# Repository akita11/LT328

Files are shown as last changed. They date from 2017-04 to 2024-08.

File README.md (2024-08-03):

# LED Tile328の関連ファイル。

## インストールと動作チェック

詳しい使い方は LT328man_v100.pdf を参照してください。以下は概要です。

1. ファイルをzipでダウンロード(右のほうの緑の"clone or Download"から)
2. ArduinoIDEから、スケッチ→ライブラリをインクルード→ZIP形式のライブラリをインストール、を選び、1.でダウンロードしたzipファイルを選ぶ。ライブラリに"LT328v2"が追加されていることを確認する
3. ArduinoIDEのツール→ボードから、"Arduino Pro or Pro Mini"を選び、プロセッサから"ATmega328(3.3V, 8MHz)"を選ぶ
4. LED TileとPCをmicroUSBケーブルで接続し、ArduinoIDEでシリアルポートを設定する
5. スケッチの例として"flow"を選び、コンパイルして転送すると、明るい光（レーザーポインタ光やスマホカメラのライトなど）があたったところのLEDが点灯し、本体を傾けるとその方向に模様が流れる ※使う加速度センサがMMA7660(LT328v2)の場合は、LT328v2.hでコメントアウトされている USE_MMA7660 のdefineを戻してください。ADXL345(LT328v3)の場合はそのままでOKです
6. Arduinoディレクトリ内のlibraries/LT328v2/board 以下に基板データが展開されますが、これは不要でしたら削除してください。

## ライブラリ関数の使い方

こちらを参照（※240803:サーバ設定の関係で現在閲覧できません。少々お待ち下さい）: https://ifdl.jp/akita/lt/

## お問い合わせ

使い方などについてのお問い合わせは、Junichi Akita (akita[at]ifdl.jp / @akita11)までご連絡ください。

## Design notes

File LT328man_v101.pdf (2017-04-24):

LED Tile328 (ver2)
Ver1.00 by akita11 (akita@ifdl.jp)

０．概要

特徴
・ 可視光（LED 懐中電灯やレーザーポインタ光・明るい LED 光等）を入力できます ・ 8×8 のマトリクス LED ユニットしても使用できます
・ 3 軸加速度センサが載っています（傾き等を検出可能）
・ 4 方向の連結拡張用コネクタあり（ピンヘッダやマグネット等） ・ ArduinoIDE でプログラミング可能（ライブラリあり）

１．まずは使ってみましょう

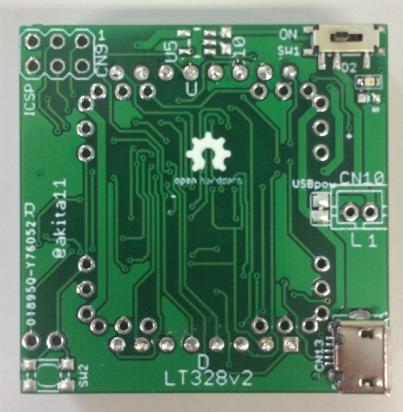
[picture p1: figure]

microUSB ケーブルを用意してください。本品の裏面にある電源スイッチが「ON」にな っていることを確認し、microUSB ケーブルを本品の microUSB コネクタに差し込み、 microUSB ケーブルの反対側を、PC の USB ポートや USB-AC アダプタ等に接続します。 マトリクス LED に広がる模様が現れ、動作が開始します。 この状態で、スマホのカメラのライトや LED 懐中電灯、レーザーポインター等の明るい 光をあてると、あたったところの LED が点灯します。また本品を傾けると、その方向に描 いたパターンが流れていきます。

２．サンプルプログラムを書き込んでみましょう

１． ArduinoIDE を http://arduino.cc からダウンロードし、PC にインストールしておき ます。（すでにインストール済みの場合は不要）
２． https://github.com/akita11/LT328 からライブラリ・サンプルプログラム一式を、この ページの右にある「Download」から zip 形式でダウンロードします。
３． ArduinoIDE の「ライブラリ」→「ライブラリをインクルード」→「.ZIP 形式のライブ ラリをインストール」から、2.でダウンロードした zip ファイルを指定します。

４． ArduinoIDE の「ツール」→「ボード」から、「Arduino Pro or Pro Mini」を選び、「ツ ール」→「プロセッサ」から、「ATmega328 (3.3V, 8MHz)」を選択します。また「ツ ール」→「シリアルポート」から、LED Tile が接続されている COM ポートを選択し ます。
５． ArduinoIDE の「ファイル」→「スケッチ例」の中の下のほうに、「LT328v2」という 項目があり、ここに LED Tile 用のサンプルが入っています。例えば”draw”を選び、 「スケッチ」→「マイコンボードに書き込む」からスケッチを書き込みます（通常の Arduino と操作は同じ）。書き込み中に点滅する LED はありませんが、しばらくする と書き込みが終了し、動作を開始します。

３．プログラミングをしてみよう

Arduino フォルダの libraries/LT328 にある LT328v2.h に、LED Tile 関連で利用できる関 数の一覧がありますので、サンプルスケッチとあわせて参照してください。基本的に、以下 のような関数があります。
・ ドットマトリクス LED の指定した箇所の LED を点灯・消灯
・ ドットマトリクス LED の指定した箇所の LED に光があたったかどうかを読む（光の 有無の基準のしきい値を設定する関数もあります）
・ 加速度センサの値を読む
・ 光があたった LED の動作を定義
・ 4 方向の通信（※この関数はまだ検証が十分に行われていません）

４．その先へ・・・

ライブラリ関数を用いることで、こちらの動画にあるような機能、例えば複数の LED Tile をまたがったパターンの移動や、ライフゲームも実現できます。ぜひご活用ください。 http://ifdl.jp/akita/lt/

５．その他の情報

ソースコード・設計データ一式は https://github.com/akita11/LT328 にありますので、必要 であればお使いください。また使い方に関するお問い合わせは akita@ifdl.jp までお願いし ます。

※本品は、技術サークル「テクノアルタ」の活動の一環として開発さ れたものです。https://www.technoalta.com/

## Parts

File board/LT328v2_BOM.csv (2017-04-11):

Part/Designator | Manufacture Part Number/Seeed SKU | Quantity
C1,C2,C3,C5,C8 | 302010138 | 5
C4,C9 | 302010158 | 2
C6 | 302010140 | 1
C7 | 302010111 | 1
CN13 | 320010005 | 1
F1 | 307010002 | 1
R1,R2,R3,R4,R5,R6,R7,R8 | 301010163 | 8
R9,R10 | 301010299 | 2
R11,R12 | 301010289 | 2
R13,R16 | 301010291 | 2
R14,R15 | 301010293 | 2
SW1 | 311030001 | 1
SW2 | 311020045 | 1
U1 | 310010005 | 1
U2 | 310070022 | 1
U3 | 310030099 | 1
U4 | 314080009 | 1
D2 | 304090043 | 1

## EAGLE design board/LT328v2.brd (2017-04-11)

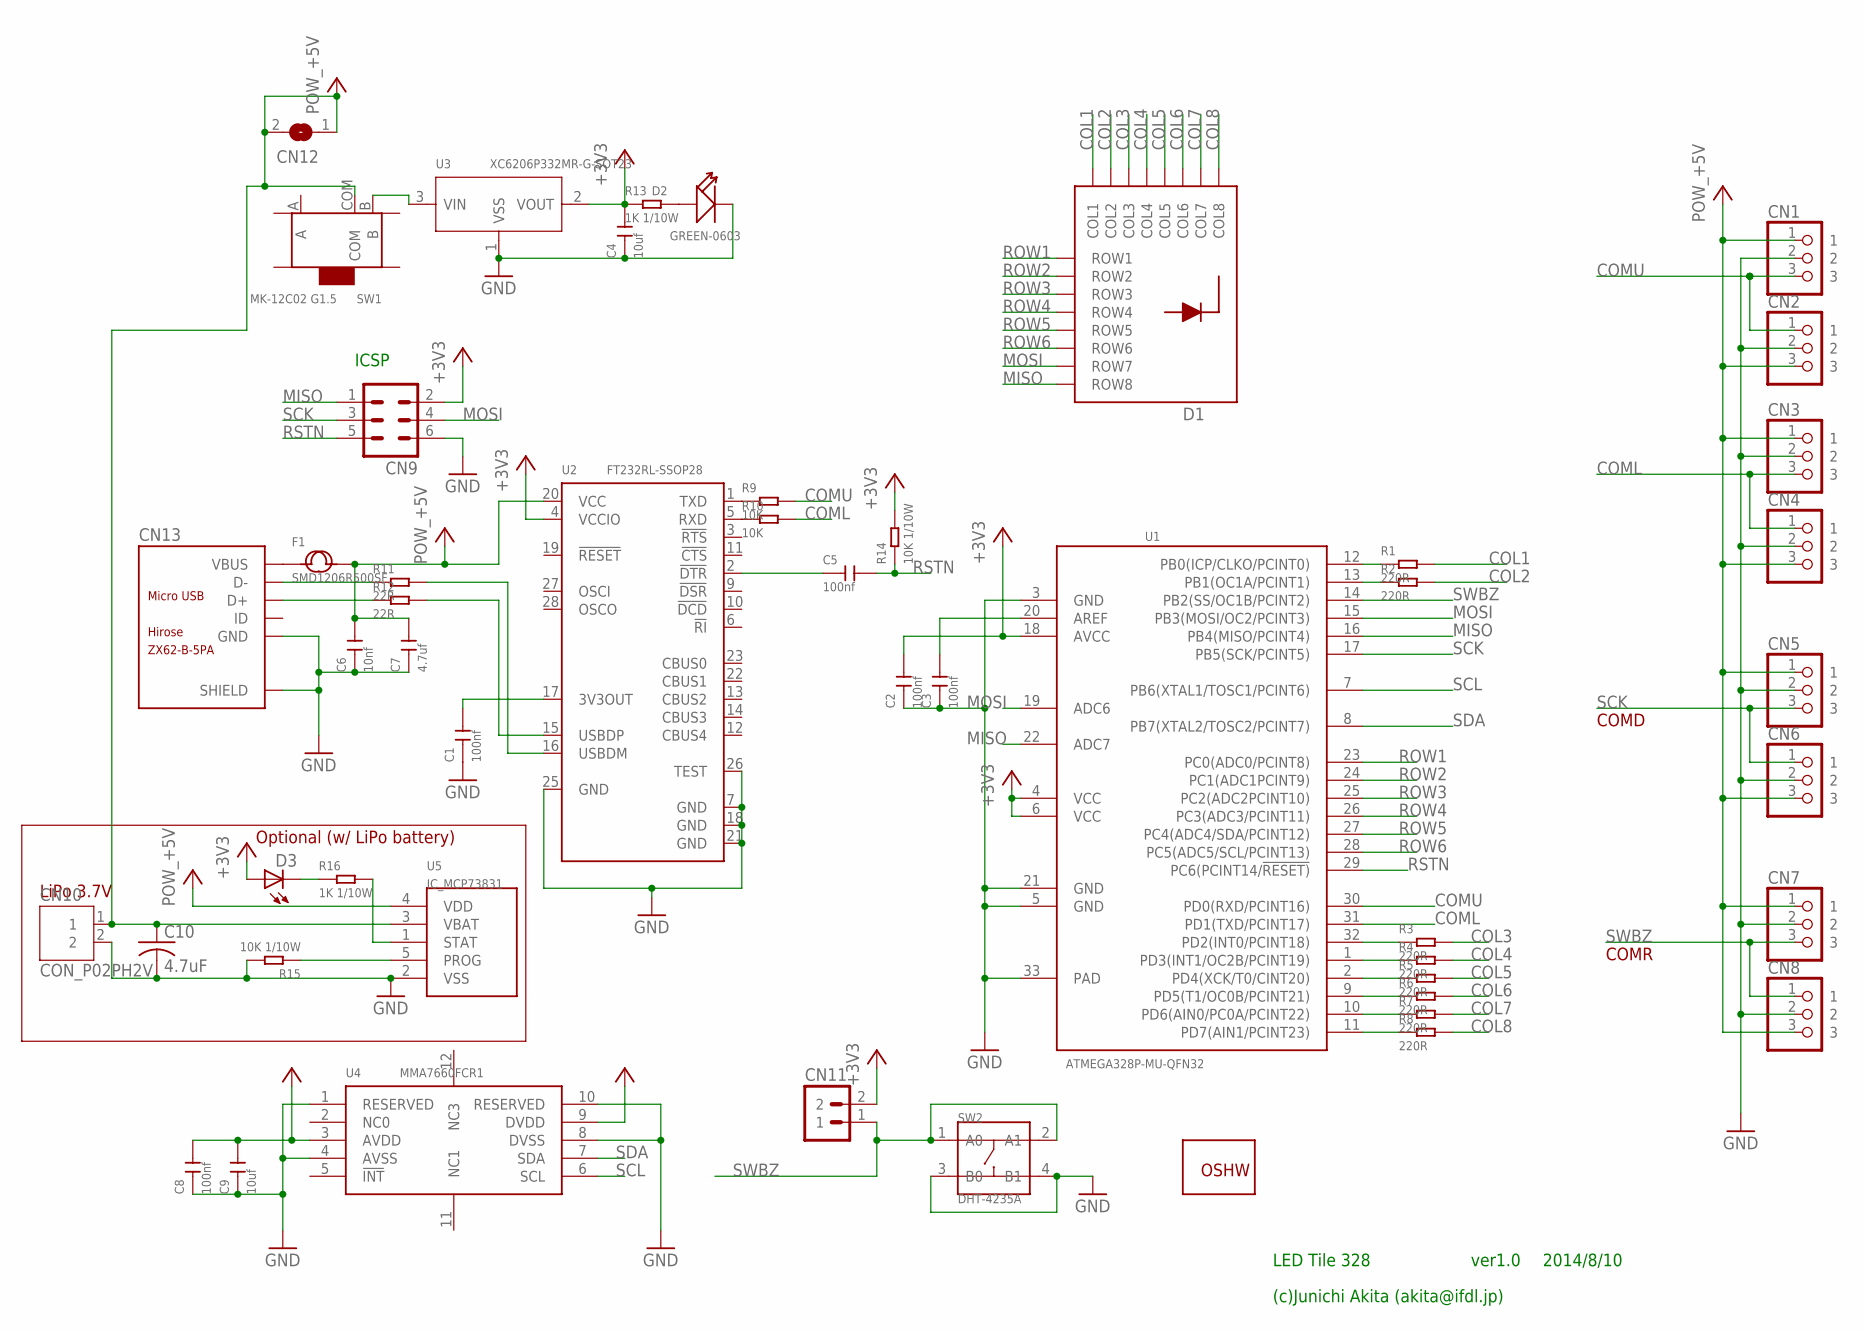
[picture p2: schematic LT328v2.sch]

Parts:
C1, C2, C3, C5, C8: 100nf; C0603
C4, C9: 10uf; C0805
C6: 10nf; C0603
C7: 4.7uf; C0603
C10: 4.7uF; C0603
CN1, CN2, CN3, CN4, CN5, CN6, CN7, CN8: CON_PINHD-1X3R; 1X03R
CN9: MA03-2
CN10: CON_P02PH2V; JST-PH2
CN11: CON_PINHD-1X2PTH; SPARKFUN_1X02
CN12: JUMPER_SJ
CN13: ZX62-B-5PA; MICRO-USB5+6P-SMD-0.65-AB
D1: LED_OSL641501BRA; TOM-1588BH
D2: GREEN-0603; LED-0603
D3: LED0603; SPARKFUN_LED-0603
F1: SMD1206R500SF; F1206
GOLD_ORB_SM1: OSHWLOGO_GOLD_ORB_SM; OSHW2
R1, R2, R3, R4, R5, R6, R7, R8: 220R; R0603
R9, R10: 10K; R0603
R11, R12: 22R; R0603
R13, R16: 1K 1/10W; R0603
R14, R15: 10K 1/10W; R0603
SW1: MK-12C02 G1.5; SW7-SMD-L6.7X2.7X3.2MM
SW2: DHT-4235A; SW4-SMD-4.2X3.2X2.5MM
U1: ATMEGA328P-MU-QFN32; QFN32G-0.5-5X5MM
U2: FT232RL-SSOP28; SSOP28-0.65-10.2X5.2MM
U3: XC6206P332MR-G-SOT23; SOT-23
U4: MMA7660FCR1; DFN10-0.5-3.0X3.0MM
U5: IC_MCP73831; SOT23-5L

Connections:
+3V3: C2.2, C4.2, C8.2, C9.2, CN9.2, CN11.2, D3.A, R13.1, R14.2, U1.4 (VCC), U1.6 (VCC), U1.18 (AVCC), U2.4 (VCCIO), U3.2 (VOUT), U4.3 (AVDD), U4.9 (DVDD)
+5V: C6.2, C7.2, C10.1, CN1.1, CN2.3, CN3.1, CN4.3, CN5.1, CN6.3, CN7.1, CN8.3, CN10.1, CN12.1, CN12.2, F1.2, SW1.COM, U2.20 (VCC), U5.3 (VBAT), U5.4 (VDD)
COL1: D1.P$13 (COL1), R1.2
COL2: D1.P$3 (COL2), R2.2
COL3: D1.P$4 (COL3), R3.2
COL4: D1.P$10 (COL4), R4.2
COL5: D1.P$6 (COL5), R5.2
COL6: D1.P$11 (COL6), R6.2
COL7: D1.P$15 (COL7), R7.2
COL8: D1.P$16 (COL8), R8.2
COML: CN3.3, CN4.1, R10.2, U1.31 (PD1(TXD/PCINT17))
COMU: CN1.3, CN2.1, R9.2, U1.30 (PD0(RXD/PCINT16))
GND: C1.1, C2.1, C3.1, C4.1, C6.1, C7.1, C8.1, C9.1, C10.2, CN1.2, CN2.2, CN3.2, CN4.2, CN5.2, CN6.2, CN7.2, CN8.2, CN9.6, CN10.2, CN13.5 (GND), CN13.P1 (SHIELD), CN13.P2 (SHIELD), CN13.P3 (SHIELD), CN13.P4 (SHIELD), CN13.P5 (SHIELD), CN13.P6 (SHIELD), D2.-, R15.2, SW2.3 (B0), SW2.4 (B1), U1.3 (GND), U1.5 (GND), U1.21 (GND), U1.33 (PAD), U2.7 (GND), U2.18 (GND), U2.21 (GND), U2.25 (GND), U2.26 (TEST), U3.1 (VSS), U4.1 (RESERVED), U4.4 (AVSS), U4.8 (DVSS), U4.10 (RESERVED), U5.2 (VSS)
MISO: CN9.1, D1.P$5 (ROW8), U1.16 (PB4(MISO/PCINT4)), U1.22 (ADC7)
MOSI: CN9.4, D1.P$2 (ROW7), U1.15 (PB3(MOSI/OC2/PCINT3)), U1.19 (ADC6)
unnamed: SW1.B, U3.3 (VIN)
unnamed: R11.2, U2.16 (USBDM)
unnamed: R12.2, U2.15 (USBDP)
unnamed: R9.1, U2.1 (TXD)
unnamed: C5.1, U2.2 (!DTR)
unnamed: C3.2, U1.20 (AREF)
unnamed: R10.1, U2.5 (RXD)
unnamed: D3.C, R16.1
unnamed: R16.2, U5.1 (STAT)
unnamed: C1.2, U2.17 (3V3OUT)
unnamed: D2.+, R13.2
unnamed: R8.1, U1.11 (PD7(AIN1/PCINT23))
unnamed: R7.1, U1.10 (PD6(AIN0/PC0A/PCINT22))
unnamed: R6.1, U1.9 (PD5(T1/OC0B/PCINT21))
unnamed: R5.1, U1.2 (PD4(XCK/T0/CINT20))
unnamed: R4.1, U1.1 (PD3(INT1/OC2B/PCINT19))
unnamed: R3.1, U1.32 (PD2(INT0/PCINT18))
unnamed: R1.1, U1.12 (PB0(ICP/CLKO/PCINT0))
unnamed: R2.1, U1.13 (PB1(OC1A/PCINT1))
unnamed: CN13.2 (D-), R11.1
unnamed: CN13.3 (D+), R12.1
unnamed: R15.1, U5.5 (PROG)
ROW1: D1.P$9 (ROW1), U1.23 (PC0(ADC0/PCINT8))
ROW2: D1.P$14 (ROW2), U1.24 (PC1(ADC1PCINT9))
ROW3: D1.P$8 (ROW3), U1.25 (PC2(ADC2PCINT10))
ROW4: D1.P$12 (ROW4), U1.26 (PC3(ADC3/PCINT11))
ROW5: D1.P$1 (ROW5), U1.27 (PC4(ADC4/SDA/PCINT12))
ROW6: D1.P$7 (ROW6), U1.28 (PC5(ADC5/SCL/PCINT13))
RSTN: C5.2, CN9.5, R14.1, U1.29 (PC6(PCINT14/!RESET))
SCK: CN5.3, CN6.1, CN9.3, U1.17 (PB5(SCK/PCINT5))
SCL: U1.7 (PB6(XTAL1/TOSC1/PCINT6)), U4.6 (SCL)
SDA: U1.8 (PB7(XTAL2/TOSC2/PCINT7)), U4.7 (SDA)
SWBZ: CN7.3, CN8.1, CN11.1, SW2.1 (A0), SW2.2 (A1), U1.14 (PB2(SS/OC1B/PCINT2))
VBUS: CN13.1 (VBUS), F1.1

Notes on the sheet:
ICSP
LiPo 3.7V
ver1.0
2014/8/10
(c)Junichi Akita (akita@ifdl.jp)
LED Tile 328
COMD
COMR
Optional (w/ LiPo battery)

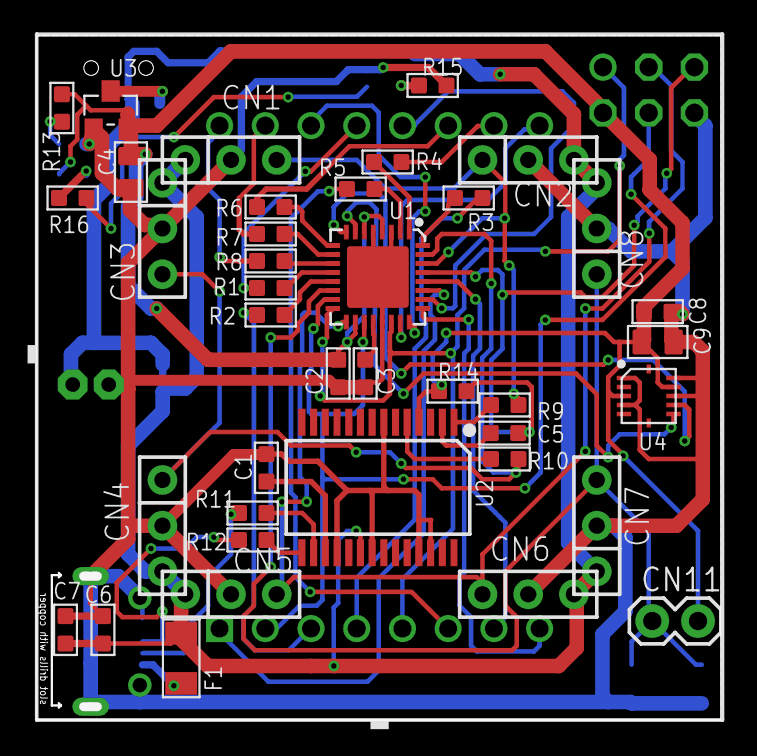
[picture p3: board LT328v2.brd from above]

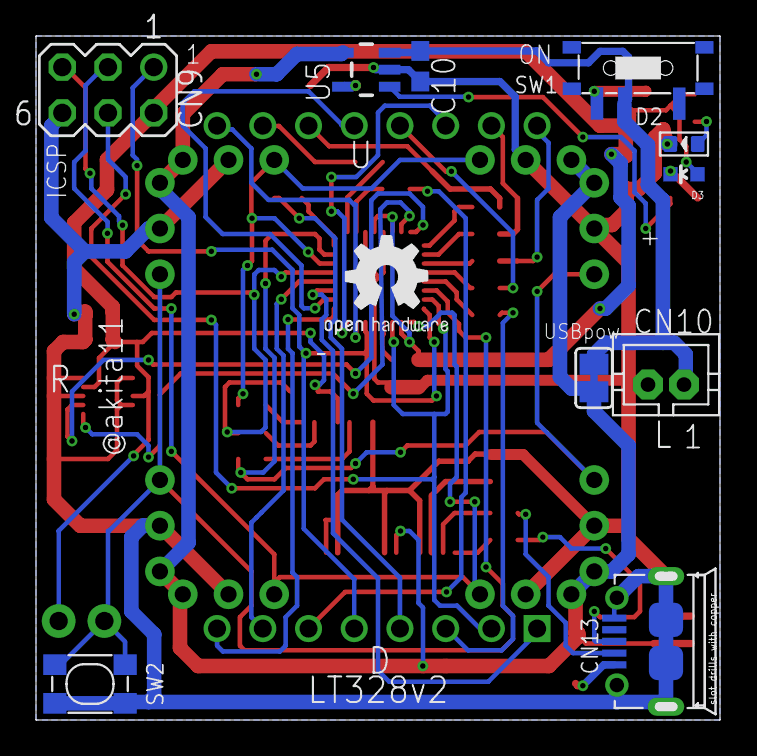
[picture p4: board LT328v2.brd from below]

Board: 2 copper layers, 38.0 x 38.0 mm, 51 parts (11 on the bottom side), 49 nets.

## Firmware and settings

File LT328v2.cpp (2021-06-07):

/*
  LT328v2.cpp - Arduino library for LED Tile, drawable 8x8 Dot Matrix LED
  based on LED_Tile328.cpp, based onDots.cpp
  Copyright 2012 akita11 (akita@ifdl.jp). All right reserved

  Dots.cpp - Arduino library for 8x8/5x7 Dot LED Matrix.
  Copyright 2010 arms22. All right reserved.
  
  This library is distributed in the hope that it will be useful,
  but WITHOUT ANY WARRANTY; without even the implied warranty of
  MERCHANTABILITY or FITNESS FOR A PARTICULAR PURPOSE. 
*/

#include <pins_arduino.h>
#include <avr/interrupt.h>
#include <LT328v2.h>
//#include <Wire.h>

void LT::set_port_dir(int pos, int num, int dir)
{
//  for BRA
//  - Col1-8(Cathode) : PB0-1/PD2-7 (via 270ohm)
//  - Row1-8(Anode)   : PC0-5/PB3-4 (ADC0-7)
  if (pos == PORT_ROW){
    if (dir == PORT_OUT){
      if (num > 7){DDRC |= 0x3f; DDRB |= 0x18;}
      else{ if (num < 6) DDRC |= 1 << num; else DDRB |= 1 << (num - 3); }
    }
    else if (dir == PORT_IN){
      if (num > 7){DDRC &= ~0x3f; DDRB &= ~0x18;}
      else{ if (num < 6) DDRC &= ~(1 << num); else DDRB &= ~(1 << (num - 3));}
    }
  }
  else if (pos == PORT_COL){
    if (dir == PORT_OUT){
      if (num > 7){ DDRD |= 0xfc; DDRB |= 0x03;}
      else{ if (num < 2) DDRB |= 1 << num; else DDRD |= 1 << num; }
    }
    else{
      if (num > 7){ DDRD &= ~0xfc; DDRB &= ~0x03;}
      else{ if (num < 2) DDRB &= ~(1 << num); else DDRD &= ~(1 << num); }
    }
  }
}

void LT::set_port_value(int pos, int num, int value)
{
//  for BRA
//  - Col1-8(Cathode) : PB0-1/PD2-7 (via 270ohm)
//  - Row1-8(Anode)   : PC0-5/PB3-4 (ADC0-7)
  if (pos == PORT_ROW){
    if (value == 1){
      if (num > 7){PORTC |= 0x3f; PORTB |= 0x18;}
      else{ if (num < 6) PORTC |= 1 << num; else PORTB |= 1 << (num - 3); }
    }
    else{
      if (num > 7){PORTC &= ~0x3f; PORTB &= ~0x18;}
      else{
	if (num < 6) PORTC &= ~(1 << num); else PORTB &= ~(1 << (num - 3));
      }
    }
  }
  else if (pos == PORT_COL){
    if (value == 1){
      if (num > 7){ PORTD |= 0xfc; PORTB |= 0x03;}
      else{ if (num < 2) PORTB |= 1 << num; else PORTD |= 1 << num; }
    }
    else{
      if (num > 7){ PORTD &= ~0xfc; PORTB &= ~0x03;}
      else{ if (num < 2) PORTB &= ~(1 << num); else PORTD &= ~(1 << num); }
    }
  }
}

LT::LT(void)
{
  _row = 0; _col = 0;
  _phase = 0;
  _raw_x = 0;
  _raw_y = 0;
  _raw_value = 0;
  _raw_value_max = 0;
  _f_raw_ready = 1;
  for (int i = 0; i < 8; i++) _th[i] = 60; // set 'default' threshold
  mode = LT_DRAW_MODE_NONE;
}

void LT::begin(uint8_t f)
{
  uint8_t i;

  set_port_value(PORT_ROW, 8, 0);
  set_port_value(PORT_COL, 8, 0); //?
  set_port_dir(PORT_ROW, 8, PORT_OUT); 
  set_port_dir(PORT_COL, 8, PORT_OUT); 
  clear();

  if (f == 1){
    for (uint8_t dir = 0; dir < 4; dir++){
      com_set_dir(dir, COM_RX);
      com_tst[dir] = 0;
      com_rst[dir] = 0;
      com_pr[dir] = 0;
      com_pb[dir] = 0;
      //      com_prb[dir] = 0;
      //      com_pbb[dir] = 0;
    }
  }
  com_operation = f;

  //  pinMode(10, INPUT_PULLUP); // for SW
  DDRB |= 0x04; PORTB |= 0x04;
  
  LT::active_object = this;

  TCCR1A = 0; // clear control register A 
  TCCR1B = _BV(WGM13); // set mode as phase and frequency correct pwm, stop the timer
  //  ICR1 = 2804;
  //  ICR1 = 3300; // 8MHz/2/3300=1.2kHz:825us / 825us*3*8=19.8ms/frame
  ICR1 = 3500;
  //  ICR1 = 3840; // 23ms/frame (43.4fps)
  TCCR1B &= ~(_BV(CS10) | _BV(CS11) | _BV(CS12));
  TCCR1B |= _BV(CS10); // no prescaler
  TIMSK1 = _BV(TOIE1); // sets the timer overflow interrupt enable bit

  DIDR0 = 0xff; // disable digital input for ADC0-7 input pins

  ADMUX = 0x60; // Vref=AVCC, left-adjust result
  //  ADMUX = 0xe0; // Vref=Vbg(1.1V), left-adjust result

  // ADC=13clk
  ADCSRA = 0x82; // ADC clock = 8MHz/4 = 2MHz
  ADCSRB |= 0x80; // ADC high speed mode
  ADCSRA |= _BV(ADSC); while ((ADCSRA & _BV(ADSC))); // initial conversion
  _f_raw_ready = 1;
  set_port_value(PORT_ROW, 8, 1); set_port_dir(PORT_ROW, 8, PORT_OUT);

  set_threshold(90); // default threshold
  i2c_setup();
#ifdef USE_ACC_MMA7660
  // initilization of MMA7660
  i2c_sendT();
  i2c_write(ACC_ADDR << 1);
  i2c_write(0x07); i2c_write(0x01); // active mode
  i2c_sendP();
#else
  // initialization of ADXL345
  i2c_sendT();
  i2c_write(ACC_ADDR << 1);
  //  i2c_write(0x16); i2c_write(0x25);
  i2c_write(0x2d); i2c_write(0x08); // Measure mode
  i2c_sendP();
  i2c_sendT();
  i2c_write(ACC_ADDR << 1);
  i2c_write(0x31); i2c_write(0x04); // +-2g, MSB-adjusted
  i2c_sendP();
#endif
}

void LT::end(void)
{
  TIMSK1 &= ~_BV(TOIE1); // disable Timer1 interrupt
  TCCR1B &= ~(_BV(CS10) | _BV(CS11) | _BV(CS12)); // stop Timer1
  LT::active_object = 0;
}

void LT::write(int x, int y, int value)
{
  uint8_t msk;
  msk = 1 << x;
  if (value == 1) pat[y] |= msk; else pat[y] &= ~msk;
}

void LT::write(int y, int value)
{
  pat[y] = value;
}

void LT::write(int y, const int values[], int size)
{
  uint8_t i;
  for(i=0;i<size;i++)
    pat[(y++) & 0x07] = values[i];
}

uint8_t LT::read(int x, int y)
{
  if (pat_in[y] & (1 << x)) return(1); else return(0);
}

uint8_t LT::read_raw(int x, int y)
{
  _raw_x = x; _raw_y = y;
  _f_raw_ready = 0;
  while(_f_raw_ready == 0);
  return(_raw_value);
}

uint8_t LT::read_raw_max(int x, int y)
{
  return(read_raw_max(x, y, 30));
}

uint8_t LT::read_raw_max(int x, int y, int N)
{
  int i;
  uint8_t v;
  _raw_value_max = 0;
  for (i = 0; i < N; i++){
    v = read_raw(x, y);
    if (v > _raw_value_max) _raw_value_max = v;
  }
  return(_raw_value_max);
}

uint8_t LT::read_raw_max(int N)
{
  int i;
  uint8_t v;
  _raw_value_max = 0;
  _raw_x = 8;
  for (i = 0; i < N; i++){
    _f_raw_ready = 0;
    while(_f_raw_ready == 0);
  }
  return(_raw_value_max);
}

uint8_t LT::read_raw_max(void)
{
  return(read_raw_max(30));
}

void LT::clear(void)
{
  uint8_t y;
  for(y=0;y<8;y++){
    pat[y] = 0;
    pat_in[y] = 0;
    _pat_in0[y] = 0;
  }
  _row = 0; _phase = 0;
}

void LT::set_threshold(int th)
{
  for (int i = 0; i < 8; i++) _th[i] = th;
}

void LT::set_threshold(int th0, int th1, int th2, int th3,
		     int th4, int th5, int th6, int th7)
{
  _th[0] = th0; _th[1] = th1; _th[2] = th2; _th[3] = th3;
  _th[4] = th4; _th[5] = th5; _th[6] = th6; _th[7] = th7;
}

void LT::set_threshold(int th[])
{
  for (int i = 0; i < 8; i++) _th[i] = th[i];
}
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

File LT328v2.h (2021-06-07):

/*
  LED_Tile328.h - Arduino library for LED Tile, drawable 8x8 Dot Matrix LED
  based on Dots.h
  Copyright 2014 akita11 (akita@ifdl.jp). All right reserved

  Dots.h - Arduino library for 8x8/5x7 Dot LED Matrix.
  Copyright 2010 arms22. All right reserved.
  
  This library is distributed in the hope that it will be useful,
  but WITHOUT ANY WARRANTY; without even the implied warranty of
  MERCHANTABILITY or FITNESS FOR A PARTICULAR PURPOSE. 
*/

#ifndef LT328V2_H
#define LT328V2_H

// uncommenct "USE_ACC_MMA7660" for LT328v3 (using ADXL345)
//#define USE_ACC_MMA7660 // use Freescale's MMA7760 as accelerometer

#include <inttypes.h>

// Dot matrix LED: OSL641501-BRA] (Akizuki's I-05163)
// Connections:
// * ATmega328P = ArduinoNano/ArduinoMini/LT328 etc.
//  - Col1-8(Cathode) : PB0-1/PD2-7 (via 270ohm)
//  - Row1-8(Anode)   : PC0-5/PB3-4 (ADC0-7)

//   (0,0) ... (7,0) : pat[0](LSB=(0,0), MSB=(7,0)
//   ...       ...     ...
//   (0,7) ... (7,7) : pat[7](LSB=(0,0), MSB=(7,7)

#define LT_DRAW_MODE_NONE    0
#define LT_DRAW_MODE_DRAW    1
#define LT_DRAW_MODE_TOGGLE  2

#define PORT_ROW 0
#define PORT_COL 1
#define PORT_OUT 0
#define PORT_IN  1

#define COMU 0
#define COMD 1
#define COML 2
#define COMR 3
#define COM_TX 0x01
#define COM_RX 0x02
#define COM_RXBUF 16


#ifdef USE_ACC_MMA7660
#define ACC_ADDR 0x4c
#else
//#define ACC_ADDR 0x1d
#define ACC_ADDR 0x53
#endif

class LT
{
private:
  uint8_t _row, _col, _phase;
  uint8_t _th[8], _pat_in0[8];
  volatile uint8_t _raw_x, _raw_y, _raw_value, _raw_value_max, _f_raw_ready;
  void set_port_dir(int pos, int num, int dir);
  void set_port_value(int pos, int num, int value);

  void com_set_dir(uint8_t dir, uint8_t md);
  void com_set_pin(uint8_t dir, uint8_t md);
  uint8_t com_read_pin(uint8_t dir);
  uint8_t com_operation;
  uint8_t com_rbuf[4][COM_RXBUF];
  uint8_t com_pr[4];
  uint8_t com_pb[4];
  volatile uint8_t com_tst[4]; // tx status (0=idle, 1=8 in transmit)
  volatile uint8_t com_rst[4]; // rx status (0=idle, 1=8 in receive)
  uint8_t com_txd[4];
  void i2c_delay();
  void i2c_setup();
  void i2c_sendT();
  void i2c_sendP();
  uint8_t i2c_write(uint8_t d);
  uint8_t i2c_read(uint8_t ack);
  void setSDA(uint8_t x);
  void setSCL(uint8_t x);
  uint8_t readSDA();

public:
  LT();
  void update(void);

  uint8_t pat[8]; // output pattern
  uint8_t pat_in[8]; // input pattern
  uint8_t mode; // draw mode (LT_DRAW_MODE_{NONE,DRAW,TOGGLE}

  void begin(uint8_t f); // start LED Tile
  void end(void); // stop LED Tile

  void write(int x, int y, int value); // draw(1)/erase(0) dot at (x, y)
  void write(int y, int value); // set pat[y] as value
  void write(int y, const int values[], int size);  // fill pattern

  // functions for serial communication
  uint8_t read(int x, int y); // read 1/0 at (x, y)
  uint8_t read_raw(int x, int y); // read raw value at (x, y)
  uint8_t read_raw_max(int x, int y);  // raw max at (x, y) (in 30 cycle)
  uint8_t read_raw_max(int x, int y, int N);  // raw max at (x, y) in N cycle
  uint8_t read_raw_max(int N);  // raw max in all area in N cycle
  uint8_t read_raw_max(void);  // raw max in all area (in 30 cycle)

  void set_threshold(int th); // set single threshold for all columns
  void set_threshold(int th0, int th1, int th2, int th3,
		     int th4, int th5, int th6, int th7); // set each threshold for each column
  void set_threshold(int th[]); // set each threshold for each column
  void clear(void); // clear pattern

  int get_acc(uint8_t axis);

  int read_sw();  

  static LT *active_object;

  // functions for serial communication
  void com_write(uint8_t dir, uint8_t d);
  int com_available(uint8_t dir);
  uint8_t com_read(uint8_t dir);
  void com_process(void);
  //  uint8_t overflow();
};

#endif	// LT328V2.h

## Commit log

2017-04-11 readmeの追加
2017-04-11 readmeの追記
2017-04-11 readmeの誤字を修正
2017-04-11 readmeを修正（いったん削除）
2017-04-11 不要ファイルの整理、readmeの再追加
2017-04-11 readmeの整形
2017-04-11 基板データの追加
    [LT328v2.brd, LT328v2.sch, LT328v2_BOM.csv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]
2017-04-17 マニュアルの追加
2017-04-24 マニュアルの説明の補足を追記
2017-04-24 マニュアルの微調整。
2021-06-07 デフォルトの加速度センサをADXL345に変更
    MMA7660を使う場合は、LT328v2.hの USE_MMA7660 のdefineを戻す
2021-06-07 使う加速度センサについてREADME.mdに追記
2021-06-07 flow.inoを修正。SWでリセットを追加
2021-06-07 README.mdの連絡先表記を修正
